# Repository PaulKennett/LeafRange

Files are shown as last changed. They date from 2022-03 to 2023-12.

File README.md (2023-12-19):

# LeafRange
A better range "guess-o-meter" for early Nissan Leaf cars

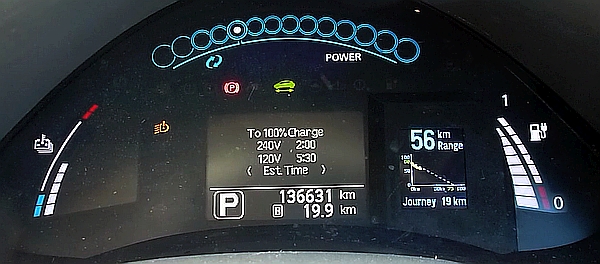
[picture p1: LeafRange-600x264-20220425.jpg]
LeafRange display installed


This project follows on from (and compliments) my earlier [LeafSOCdisplay](https://github.com/PaulKennett/LeafSOCdisplay) project, which grew from [CANa Display for Nissan LEAF](https://ev-olution.yolasite.com/CANa.php) © Copyright EV-OLUTION

The project uses an Ardunio Micro (or Mini Pro, or Mega2650) with a 160x128 pixel TFT display and a MCP2515 CAN-bus module to passively listen to the Car-CAN data bus and use the info to provide a more rational range estimate. The display is mounted in a 3D printed frame that fits *inside* the main dash unit and covers the old range estimate (ie., the "guess-o-meter") with a better range estimate based on battery capacity and temperature. There's also an optional frame that allows the display to be mounted in the corner of the dash, so you can see both the standard Guess-O-Meter and my range estimate.

YouTube drive demo: https://www.youtube.com/watch?v=xt2o3SWRRq8

YouTube hardware show & tell: https://www.youtube.com/watch?v=k4QYvayp_lU

## Features

* range estimate is not stupidly optimistic at the start of your journey (which is usually when you most want it to be rational). You won't see the range estimate drop 10 km after driving the first 1km like the built-in Guess-O-Meter does.
* range estimate does not disappear when the battery dips below 20% (to be replaced by the flashing ---). You get an accurate range estimate down to 0 km. However; there's no buffer below that - so you can't drive another 10 km on "empty" like in a petrol car.
* range chart that shows how well the estiimate matches reality (stores jouurney data in EEPROM over multiple drives)
* shows battery pack temperature in Centigrate (more understandable than the temp "bars") when the battery is cold or hot
* auto-starts a journey odo (multiple trips on a single charge)
* range calculation factors in: battery State of Charge, battery State of Health, and battery temperature (see https://github.com/PaulKennett/LeafRange/wiki/Notes}

The significance of the range chart feature is that it makes it much easier to adjust your driving to achieve a desired range.

### For example
Say you need to drive 75 km in your 2011 Leafster. You charge to "100%" which gives you a rage estimate of 82km range on my LeafRange display (not that bad for an old gen 1.0 Leaf). The guess-o-meter would be saying something like "103km" which would be a bold-faced lie. 

So you head off, stopping at a few places along the way (my display saves range and odo data along the way). About half way there you notice that the chart is showing you're actually trending _below_ the initial estimate line - meaning you should start to ease off the speed a little so that you won't run short. 

On the other hand - if you see that you're driving _above_ the initial estimate line then you know you have plenty of capacity to spare so can afford to drive faster.

### Limitations

THe range formula is simple; it's only factors are battery capacity, battery SOH and batter temperature. It doesn't know about terrain, weather, driving conditions, car weight, etc. The key benefits are; (a) it's not stupidly optimistic at the start of a drive, (b) it doesn't stop working at the bottom end, and (c) the chart allows you to adjust your driving behaviour to achieve a desired range. All those things improve your confidence and reduce range anxiety.

The raw_Gids variable is stored as a single byte so can't go above 255. A brand new 24 kWh Leaf has about 281 Gids when full. This puts an upper bound on the range it can deal with of about 130 km (about 160 km on the GOM).

## Hardware

1. Arduino Micro, Mini Pro, or Mega2560 (use a Mega2560 for development, use a Micro or Mini Pro for use in the car as it boots up much faster and uses less power)
2. MCP2515 (CAN bus module)
3. 1.8 inch TFT display 160x128 pixels (like this https://www.aliexpress.com/item/4000016800528.html)
4. TXS0108E 8 Channel Logic Level Shifter (https://www.aliexpress.com/item/4001131536726.html)
5. 10 Position Flat Flex Cable Assembly Receptacle to Solder Tab 4.00" (101.60mm) https://www.digikey.co.nz/product-detail/en/te-connectivity-amp-connectors/A9AAT-1004F/A9AAT-1004F-ND/137494
6. 5V to 3.3V DC-DC Step-Down Power Supply module (https://www.aliexpress.com/item/4001039310587.html)
7. 70CM 10P IDC Flat Ribbon DATA Cable 2.54mm (https://www.aliexpress.com/item/32891063802.html)
8. Male DC3 10 Pin 2x5Pin Right Angle Double Row Pitch 2.54mm (https://www.aliexpress.com/item/32945804425.html)
9. 3D printed frame for the display (https://www.myminifactory.com/object/3d-print-nissan-leaf-range-graph-display-154555)
10. 3D printed project box DRAFT (https://www.tinkercad.com/things/lRlt66oEZCM-leafrange-box-v16 - I'll provide a better link soon}
11. PBC motherboard for a Pro Micro or Pro Mini Arduino (Gerber file provided above or https://oshwlab.com/paulkennett/LeafRange-for-Micro)
12. PCB for level shifter module (Gerber file provided above - you could use https://jlcpcb.com/ to make them)
13. OBD2 plug (like this https://www.aliexpress.com/item/32865761651.html)
14. 97% Mini DC-DC 15V 12V 9V 7.4V to 5V 4A Step-down Power Module https://www.aliexpress.com/item/4001313603033.html

[Parts list](https://docs.google.com/spreadsheets/d/e/2PACX-1vS2Nyihl8SLagP5YnfhvbngJ51losEeNEex3Urd8iOHfg4pMDlcg-ZONYQ7dYSHcnsXQ2ahFD6JTfKS/pubhtml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) with indicative NZ$ and US$ prices (as at 11 May 2022)

Note: LeafRange_v117.ino fills 99% of program memory on a Micro board, 85% on a Por Mini board and 11% on a Mega 2560 board. If I come up with any new fetures ideas I'll need to drop using the Micro board and foxcus on the Pro Mini.

## Relation to the LeafSOC project

The LeafRange project started out as a fork of the LeafSOC project (with a larger 3.3V TFT display to replace the 5V OLED display). So the LeafRange motherboard has been designed to also be used for the LeafSOC project. The on-board jumpers allow you to switch between Car-CAN (for LeafRange) or EV-CAN (for LeafSOC). 

Also: 
* the latest LeafRange motherboard also has the correct dimensions for the OBD2 plug holes. T
* the LeafSOC project uses a 5V OLED display so you can leave the 5V-to-3.3V DC-DC converter off  

## Todo
- see the Wiki Todo page https://github.com/PaulKennett/LeafRange/wiki/Todo

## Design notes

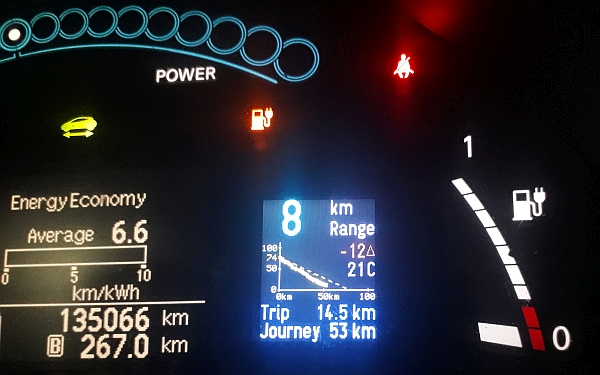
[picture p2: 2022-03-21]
LeafRange_2022-02-21-600x375.jpg

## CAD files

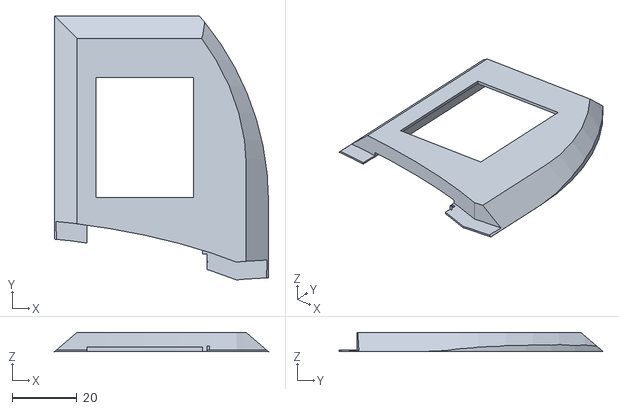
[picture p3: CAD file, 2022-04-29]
LeafRange TFT in-dash frame v03.stl
66.0 x 81.4 x 6.00

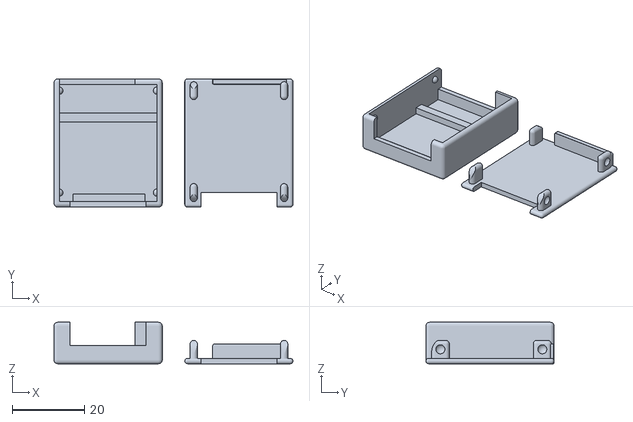
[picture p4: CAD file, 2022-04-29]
LeafRange level shifter box v04.stl
66.2 x 35.5 x 11.5

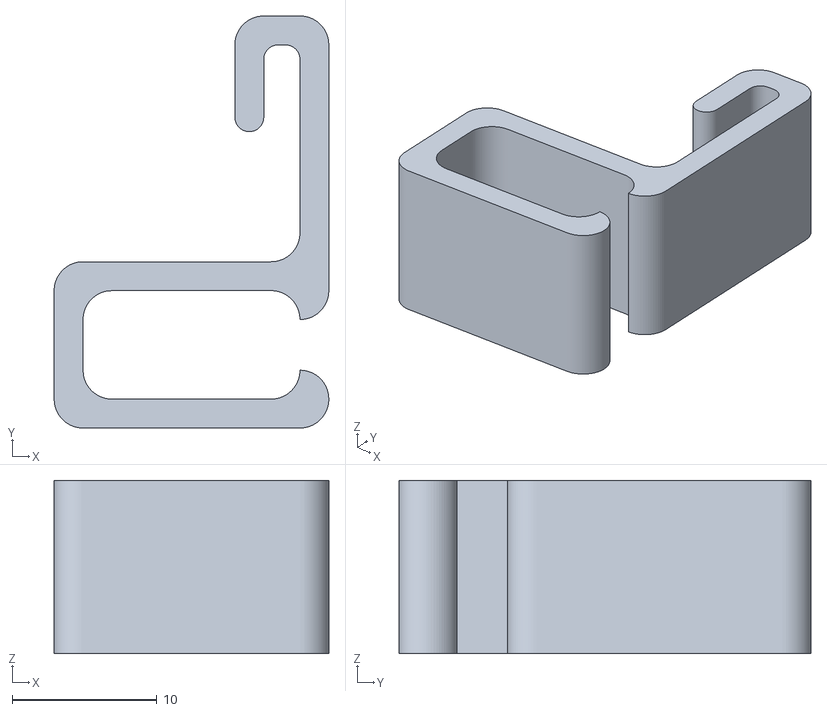
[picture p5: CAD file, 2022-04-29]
Leaf ODB2 cable clip v03.stl
19.0 x 28.5 x 12.0

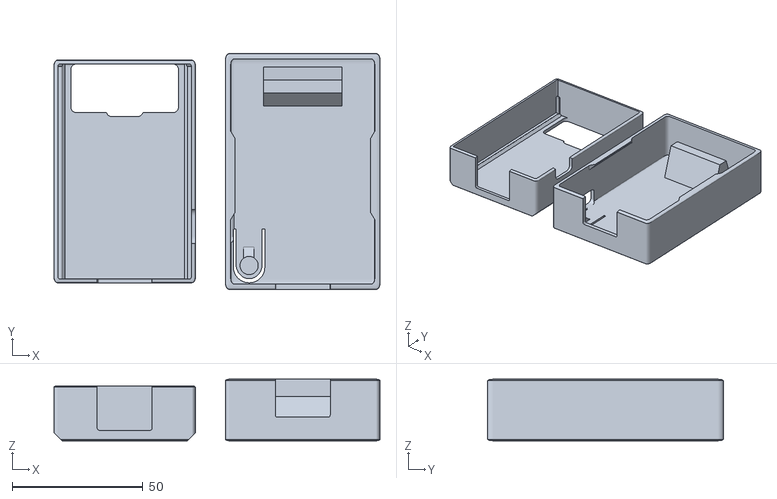
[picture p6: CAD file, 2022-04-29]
LeafRange box for Micro-Mini v04.stl
124.5 x 90.0 x 23.5

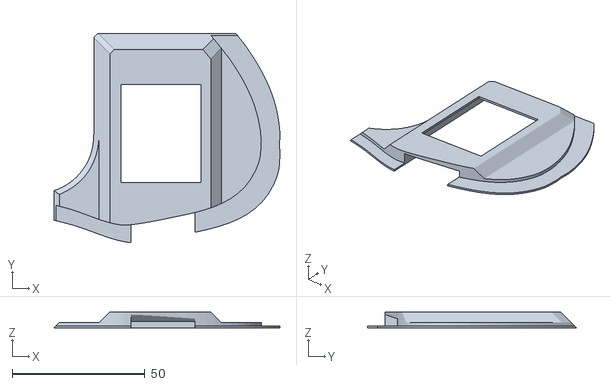
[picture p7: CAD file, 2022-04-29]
LeafRange TFT on-dash frame v11.stl
85.0 x 78.7 x 6.00

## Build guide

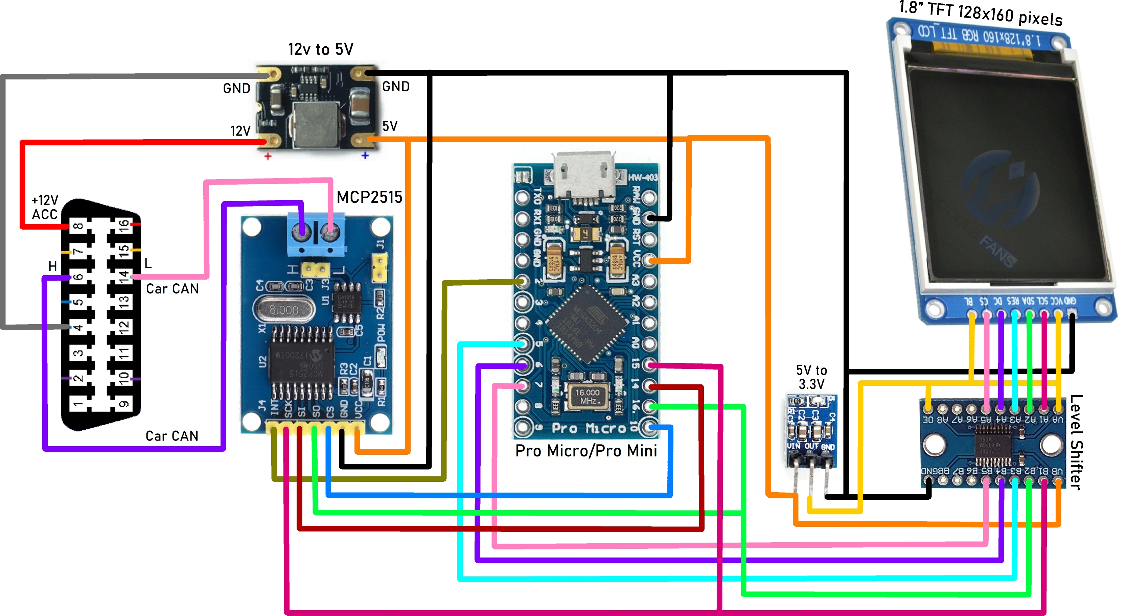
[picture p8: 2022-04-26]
LeafRange wiring diagram 2022-04-26.jpg

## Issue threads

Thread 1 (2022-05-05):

Intermittent interference on Gerber_PCB_LeafRange Micro v0.3C_2022-04-28.zip

PaulKennett, 2022-05-05:
I'm seeing some weird errors on two boards made up using the motherboard.

The range chart shows datapoints in random spots on the graph. After searchign for program bugs my latest hunch is it's a hardware issue.

My current hypothesys is that this is due to interference between the 12V to 5V buck module and the MCP2515 CAN module. This motherboard design has the buck module mounted facing up and the CAN module facing down, directly over it.

I suspect the cheap buck converter (ie a switch mode power supply) is emitting a lot of RF noise directly at the MCP2515 chip. Also the CAN lines from the OBD2 plug run directly under the buck module.

PaulKennett, 2022-05-11:
**Work-around**

Un-solder the module from the motherboard (v0.3C) and have it floating away from the CAN lines and MCP2515. I don't yet know how afar away it needs to be. I've done this to a couple of prototypes and it resolved the data error issue.

**Solution**

I've produced a new version of the motherboard (v0.4A) which moves the buck module further away from the MCP2515.

Hopefully that'll do - but I haven't tested the new board-yet.

Closed 2022-05-11.

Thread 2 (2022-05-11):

X axis scale does no go beyond 100 km

PaulKennett, 2022-05-11:
For cars that (*gasp!*) get more than 100 km range - the X and Y axis scales need to auto-set up to fit the available range.

Could use the battery SOH% value to estimate max range.

1. 66% SOH - my 2011 car max GOM range is 105 km
2. 81.7% SOH - my 2011 car max GOM range was 141 km
3. 83.07 SOH - my 2011 car max GOM range was 150 km
4. 85% SOH - Jodene's 2014 car max GOM is 140 km
5. ??% SOH - Martins 2014 car max GOM is ??? km
6. ??% SOH - Tom's 201? car max GOM is ??? km
7. 81% SOH - John's 2015 car max GOM range is 147 km
8. 79% SOH - John's 2015 car max GOM range is 135 km
9.  ??% SOH - Merewyn's 2011 car max GOM range is ??? km

Here's my rough formula:

max range = 2.23 * SOH - 40

Would help to have a bit more data on battery SOH% vs Guess-O-Meter max range (from cars with less than my 66 SOH%.

PaulKennett, 2022-05-16:
Version 116 fixes this limitation by making the x and y axis scale to 110% that of the initial range.

Closed 2022-05-16.

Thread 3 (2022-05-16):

raw_Gids is stored in a byte

PaulKennett, 2022-05-16:
the raw_gids variable is stored in a byte variable type so the max Gid vlur possible is 255.

A brand new 24kWh Leaf had 281 Gids. My 2011 Leaf had 225 Gids back in 2019 when fully charged.

Are there any 2017 24kWh Leafs with more than 255 Gids left? Maybe - but they probably wont be interested in this project.

If I had to store raw_Gids as a two byte variable in the 1024 byte Micro/Pro Mini EEPROM it would mean I could only store 335 Gid&Odo entries, instead of the 503 entries currently.

PaulKennett, 2022-05-16:
I think this limitation is OK for now.

But, if I ever upgraded to a system with a larger EEPROM then it would be worth switching to storing Gids in 2 bytes.

Closed 2022-05-16.

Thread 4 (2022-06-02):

Intermittent: when car is on but not just sitting for a while LeafRange can slip in to Charging graph mode

PaulKennett, 2022-06-02:
Which causes the Journey odo to reset to zero

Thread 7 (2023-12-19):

Possible improvements

klasrocket, 2023-12-19:
Hi.

Got inspired by your project and started puting toghether something that could also work for 2018+ 40KWh leafs, as I own an old 2012 but borrows a 2018 sometimes for longer trips.
I had the idea to use esp32 instead of arduino for a few reasons, ie. being able to share SoC readings with other services wirelessly, maybe home assistant and/or a better route planner, also esp32 require fewer components, as it's 3.3v and has can-controller built in.
Got it working fairly well at the old leaf but just realized that the newer leafs need polling on the canbus to get anything out at all. Trying to get that working now with help of dalas repo and links: https://github.com/dalathegreat/leaf_can_bus_messages

PaulKennett, 2023-12-19:
I've been thinking about jumping to esp32 also. And I've been borrowing a 30kWh Leafs from time to time. Keen to see what you come up with.

klasrocket, 2023-12-19:
Another thing that might be useful with esp32 is the ability to use a browser on a phone or tablet instead of display, or in combination for more details.
Just managed to get the polling right to read back shifter position so at least some progress. Getting late here in sweden but will contiune a bit the coming days. Hopefully I can get back with something useful in a bit.

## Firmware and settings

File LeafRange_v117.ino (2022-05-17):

// ================================================
// LeafRange by Paul Kennett, 2022
/*
  Started from "CANa Display for Nissan LEAF"  https://ev-olution.yolasite.com/CANa.php © Copyright EV-OLUTION
  Modified by Paul Kennett to use a 128x160 TFT dsiplay and added Range functions.
  For Arduino Mega2650, Micro and Pro Mini boards
  For Arduino Micro and Mini - works by subtracting debug data out to serial port code
  The MCP2515 CAN module is connected to Vehicle-CAN ("Car-CAN") on the OBD2 socket
  See https://paulkennett.github.io/LeafRange/ for full project details

  v117 17 May 2022  refining the charge graph routine
  v116 16 May 2022  made the range chart auto scale to fit initial range
  v115 15 May 2022  refining the charge graph routine
  v114 14 May 2022  made the x & y axis auto-scale
  v113 25 Apr 2022  moved Odo test display section off to a function (cleaner)
  v112 19 Apr 2022  fixed temperature display bug
  v111 18 Apr 2022  Aaargh! Why doesn't the odo reading in Jodene's 2014 Leaf work anymore?!?
  v111 17 Apr 2022  moved counter_pointer in EEPROM to location 4 (and 5) to see if that fixes new odo bug
  v110 16 Apr 2022  fixed bugs produced yesterday
  v109 15 Apr 2022  fixed bugs during drive to Tauranga in Gen 1.1 Leaf
  v108 10 Apr 2022  trying to fix charge/drive mode switching
  v107 10 Apr 2022  watthours_per_gid now derived from raw_battery_soh
  v106 09 Apr 2022  testing in Jodene's 2014 Leaf:
                    (1) raw_gids glitches 38 to 81
                    (2) Range is too pessimistic - need to factor in battery SOH
                    (3) Her SOH 2014 Leaf = 85, my SOH 2011 Leaf = 66
                    (4) Her WH_PER_GID = ???,   my WH_PER_GID 74.0F
  v105 06 Apr 2022  adding charge mode gridelines
  v104 06 Apr 2022  change charging mode x axis to 0 to 50 minutes
  v103 02 Apr 2022  Fixing Charging mode bug: after fast charge did not reset pionter when driving
  v102 31 Mar 2022  Fixing bug: Charging mode while driving
  v101 31 Mar 2022  Fixing bugs in the Charging mode
  v100 30 Mar 2022  starting to work on Charging mode feature
  v88  25 Mar 2022  replacing range_error with range + journey_odo on x axis
  v87  24 Mar 2022  tweaked the range error UI
  v86  23 Mar 2022  tweaked some colours
  v86  20 Mar 2022  optimizing code to fit into the Micro. It works!
  v85  19 Mar 2022  tidying up
*/

#define NAME    "LeafRange"
#define VERSION "Version 117"
#define DATE    "17 May 2022"
#define AUTHOR  "Paul Kennett"

#ifdef __AVR_ATmega2560__       // Debug mode only works on the Mega2650 board. The Micro and Mini don't haven enough program memory
bool debug_mode = false;        // Serial port debug verbosity. Turn ON by changing [false] to [true]. It will slow everything down a lot.
#endif

#include <Adafruit_GFX.h>       // by Limor Fried/Ladyada for Adafruit Industries
#include <Adafruit_ST7735.h>    // Hardware-specific library for ST7735 TFT display
#include <mcp_can.h>            // OBD2 CAN module
#include <EEPROM.h>             // read/write to the EEPROM memory
#include <Fonts/Logisoso_reduced11pt7b.h>
#include <Fonts/Logisoso_compact30pt7b.h>

#define BLACK         0x0000
#define RED           0x001F
#define ORANGE        0x041F
#define GREEN         0x07E0
#define YELLOW        0x07FF
#define LIGHT_YELLOW  0x479C
#define LIGHT_BROWN   0x061D
#define GREY          0x8410
#define LIGHT_GREY    0xC618
#define LIGHTER_GREY  0xE71C
#define LIGHTEST_GREY 0xF79E
#define CYAN          0xFFE0
#define CYAN2         0x8400
#define LIGHTER_BLUE  0xFED6
#define LIGHT_BLUE    0xFE10
#define WHITE         0xFFFF

// Car-CAN (0x174,3) raw_shifter_position vlues
#define PARK          170
#define DRIVE         187
#define REVERSE       153

#define GIDS_TURTLE 8          // raw Gids-8 (the number of Gids to reach Turtle mode)
#define MILES_TO_KM 1.609344F  // conversion factor
#define CAN0_INT    2          // Set CAN0 INTerupt to pin 2
#define TFT_CS      7
#define TFT_RST     5
#define TFT_DC      6

#ifdef __AVR_ATmega2560__
#define EEPROM_SIZE 2047
#else
#define EEPROM_SIZE 1023       // currently experimenting with using just 1K of EEPROM, even on the Mega2560
#endif

#define EEPROM_ADDR_TEST 0     // EEPROM address for the test byte. If not what's expected then this must be a fresh board, so format the whole EEPROM
#define EEPROM_ADDR_DATA 4     // EEPROM address for the data pointer (2 bytes: 4 and 5)
#define EEPROM_ADDR_DATA_START 16  // EEPROM address where the raw_gids/Odo_km data starts 
#define EEPROM_ADDR_DATA_END EEPROM_SIZE  // EEPROM address where the raw_gids/Odo_km data ends (Might as well make it EEPROM_SIZE until I think of something better.)
#define EEPROM_TEST_BYTE 151   // if EEPROM(0) is not this value then assume it's a new board so will format EEPROM
#define CHARGE_TEST_OFFSET 9   // Last_Gids plus this number is compared with raw_gids (first time thru main loop) to test if the car has just been charged

#define LINE1 20               // Y position for top line of text in start-up message
#define LINE2 42               // 2nd line of text
#define LINE3 64               // 3rd line
#define LINE4 98               // 4th line
#define LINE5 120              // 5th line
#define LINE6 130              // 6th line
#define DISPLAY_WIDTH 127      // from 0
#define DISPLAY_HEIGHT 160     // from 0
#define PLOT_TOP 37            // from top of display
#define PLOT_TOP_MARGIN 20     // from top of plot space to top line
#define PLOT_BOTTOM 33         // from bottom of display
#define PLOT_BOTTOM_MARGIN 12  // 
#define PLOT_LEFT 20           // from left side of display
#define PLOT_RIGHT 0           // from right side of display [was 27]
#define FONT_HALF_HEIGHT 4     // for gridline lables
#define PUSH_BUTTON1 8         // currently used for testing

byte plot_width      = DISPLAY_WIDTH - PLOT_LEFT - PLOT_RIGHT;
byte plot_top        = PLOT_TOP + PLOT_TOP_MARGIN;
byte plot_bottom     = DISPLAY_HEIGHT - PLOT_BOTTOM - PLOT_BOTTOM_MARGIN;
byte plot_height     = plot_bottom - plot_top;
byte plot_middle     = plot_top + (plot_height / 2);
byte scale_xy        = 100; // default
float scale_y;
float scale_x;
float odo_conversion = MILES_TO_KM;

long unsigned int rx_id;       // CAN message ID
byte len;                      // data length
byte rx_buf[8];                // 8 byte
//uint16_t raw_gids;           // raw Gids from Vehicle CAN bus x5b3
//uint16_t raw_gids2;          // raw Gids from Vehicle CAN bus x5b3
byte raw_gids;                 // raw Gids from Vehicle CAN bus x5b3
byte raw_gids2;                // raw Gids from Vehicle CAN bus x5b3
unsigned long raw_odo;         // Odometer from Vehicle CAN bus x5c5
byte raw_battery_pack_temp;    // raw battery pack temperature
byte raw_battery_soh;          // battery State of Health %
byte raw_shifter_position;     // Shifter position
byte raw_cluster_units;        // is odo in km or miles?

// Some nomenclature:
// A "trip" (or "leg") means: turn the car on, do some stuff (or not), then turn the car off
// A "journey" is made up of one or more trips/legs. A journey auto-starts when you start the car after a charge session

bool first_time = true;        // used to indicate first time through the main display loop (for driving behaviour)
bool second_time = false;      // used to indicate second time through the main display loop (used for charging behaviour)
bool charging = false;         // true when charing
int range;                     // Range estimate
int range_start;               // Range at start of this journey
int range_error;               // the difference between the initial range estimate and the current range + odo
float battery_pack_temp;       // battery pack temperature
float km_per_kWh;              // km per kWh (of course the real value would change with terrain & wind, etc) now derived via battery_pack_temp
float odo_km_start;            // Odo at start of drive session (leg) [presumably this is always zero!?]
float odo_km;                  // Odo in km (leg)
float odo_km2;                 // used to compare if new value has changed from old value
// float journey_odo;             // the distance in km over the journey (multiple legs) since the car was charged
byte journey_odo;             // the distance in km over the journey (multiple legs) since the car was charged
byte journey_odo_first;        // the first value of journey_odo from EEPROM(5) [presumably this is always zero!?]
byte journey_odo_last;         // the last value of journey_odo from previous drive session (leg)
byte eeprom_gids;              // the Gids value in the EEPROM
byte eeprom_gids_last;         // the last Gids value in EEPROM
unsigned int data_pointer;     // used to cound each time some fresh data is recieved from the CAN bus
float watthours_per_gid;       // value of this is now calculated via battery SOH

// for timestamps in the debug data going out to the serial port.
unsigned long all_seconds;
int run_hours;
int run_minutes;
int run_seconds;
int secs_remaining;


MCP_CAN CAN0(10);              // Set CS for MCP2515 module to pin 10

Adafruit_ST7735 tft = Adafruit_ST7735(TFT_CS, TFT_DC, TFT_RST);


// ============================================================================================
// ============================================================================================
// ============================================================================================


void setup() {

  // temp hacking
  // EEPROM.update(EEPROM_ADDR_TEST, 0); // Uncomment this line if you want to "manually" reformat the EEPROM. Upload & run once. Then recomment this line and upload & run.



  if (EEPROM.read(EEPROM_ADDR_TEST) != EEPROM_TEST_BYTE ) { // auto-format the EEPROM the first time this sketch is run on a board
    format_eeprom();
  }

#ifdef __AVR_ATmega2560__
  if (debug_mode) {
    Serial.begin(9600);
    copy_eeprom_to_serial_port(PUSH_BUTTON1);  // dump the whole EEPROM out the derial port
  }
#endif

  pinMode(PUSH_BUTTON1, INPUT_PULLUP);    // push button on LeafRange PCB

  // read the EEPROM
  data_pointer =  read_unsigned_int_from_eeprom(EEPROM_ADDR_DATA);
  journey_odo_last = EEPROM.read(data_pointer - 2); // reading data_pointer - 2 because data_pointer gets incremented at the end of the main loop [but what if it's a newly formatted EEPROM?!]
  eeprom_gids_last = EEPROM.read(data_pointer - 1);


#ifdef __AVR_ATmega2560__
  if (debug_mode) {
    sprint_setup_data();
  }
#endif

  tft.initR(INITR_GREENTAB);  // Init ST7735S chip, "green tab" variation
  tft.setRotation(2);
  tft.fillScreen(BLACK);
  tft.setTextWrap(false);
  tft.setTextColor(YELLOW);

#ifdef __AVR_ATmega2560__
  if (debug_mode) {
    Serial.println("------------------- Initialise MCP2515 CANbus Module");
  }
#endif

  if (CAN0.begin(MCP_ANY, CAN_500KBPS, MCP_8MHZ) == CAN_OK) {
    mcp2515_boot_message(); // Show version and date. Also functions as delay to get connection to MCP CANbus module running
  } else {
    mcp2515_error_message();
  }

#ifdef __AVR_ATmega2560__
  if (debug_mode) {
    sprint_time_since_boot();
    Serial.println("----------------------------------------------------");
  }
#endif

  CAN0.setMode(MCP_NORMAL);                     // Set operation mode to normal so the MCP2515 sends acks to received data.
  pinMode(CAN0_INT, INPUT);

  tft.setCursor(44, 155); tft.print("Loading...");

#ifdef __AVR_ATmega2560__
  if (debug_mode) {
    Serial.print("===================================== end setup loop\r\n\r\n");
  }
#endif

} // End setup


// ============================================================================================
// ============================================================================================
// ============================================================================================


void loop() {


  // grab a scoop of data from the Car-CAN bus using the MCP2515

  if (!digitalRead(CAN0_INT)) {                   // If CAN0_INT pin is low, read receive buffer
    CAN0.readMsgBuf(&rx_id, &len, rx_buf);        // Read data: len = data length, buf = data byte(s)
    if (rx_id == 0x174) {
      raw_shifter_position = (rx_buf[3]);
    } else if (rx_id == 0x355) {
      raw_cluster_units = (rx_buf[6]);
      if (raw_cluster_units == 64) { // 64 = km, 96 = miles
        odo_conversion = 1;
      }
    } else if (rx_id == 0x5b3) {
      raw_battery_pack_temp = (rx_buf[0]);
      raw_battery_soh = (rx_buf[1]) >> 1;
      raw_gids = constrain((rx_buf[5]), 0, 255); // contrained to fit in one byte
    } else if (rx_id == 0x5c5) {
      raw_odo = (rx_buf[1] << 16 | rx_buf[2] << 8 | rx_buf[3]);
      if (odo_km_start == 0) {
        odo_km_start = (float)raw_odo * odo_conversion;
      } else {
        odo_km = ((float)raw_odo * odo_conversion) - odo_km_start;
      }
    }
  }
  // end grab CAN bus data

  // for testing at my desk
  /*
      raw_shifter_position = DRIVE;  // use PARK to test charging
      raw_cluster_units = 96;
      raw_battery_pack_temp = 95;
      raw_battery_soh = 66;   // my 2011 battery SOH = 66, Jodene's 2014 battery SOH = 85
      //raw_gids = 255;
      raw_gids = EEPROM.read(EEPROM_ADDR_DATA_START + 1);
      //  charging = true;
      //  raw_gids2 = 160;
  */

  // If got fresh raw_gids or odo_km - do all the stuff -------------------------------
  if ((raw_gids != 0) && (raw_gids2 != raw_gids || odo_km2 != odo_km)) {

    journey_odo = constrain(journey_odo_last + odo_km, 0, 255); // contrained to fit in a single byte

    if (!charging) {       // update data_pointer and save data to the EEPROM data array
      EEPROM.update(data_pointer, (byte)journey_odo);
      EEPROM.update(data_pointer + 1, (byte)raw_gids);
    }

    // calculate some stuff
    battery_pack_temp = (raw_battery_pack_temp / 4) - 10;
    watthours_per_gid = 52.17 + (raw_battery_soh * 0.33); // This seems to work OK (so far)
    km_per_kWh        = 5.05 + (0.1 * battery_pack_temp) - (0.0005 * (pow(battery_pack_temp, 2.1))); // formula is fudged from FlipTheFleet dataset (now tapers at higher temps)
    range             = km_per_kWh * ((raw_gids - GIDS_TURTLE) * watthours_per_gid) / 1000;

    // ----------------------------------------------------------------------------------
    if (second_time) {                    // if this is the second time thru the data loop then test if charging
      if (raw_gids > raw_gids2 && odo_km2 == odo_km && raw_shifter_position == PARK) {         // If second raw_gids value has increased then it must be charging
        charging = true;
        range_start = km_per_kWh * ((EEPROM.read(EEPROM_ADDR_DATA_START + 1) - GIDS_TURTLE) * watthours_per_gid) / 1000;
        print_static_drive_elements();
        data_pointer = EEPROM_ADDR_DATA_START;
        write_unsigned_int_to_eeprom(EEPROM_ADDR_DATA, data_pointer);
        EEPROM.update(data_pointer, 0); // reset first journey_odo value in EEPROM to zero
        journey_odo_last = 0;
        journey_odo = 0;
        EEPROM.update(data_pointer + 1, (byte)raw_gids);
        eeprom_gids_last = raw_gids;
      } else {
        charging = false;
      }
      second_time = false;
    } // end of "second time only" tasks
    // ----------------------------------------------------------------------------------

    // ----------------------------------------------------------------------------------
    // "first time only" tasks: draw a dashed line and plot stored data
    if (first_time) {                    // if this is the first time then save raw_gids to EEPROM max_gids array
      tft.fillScreen(BLACK);

      // Has the car just been charged?
      if (raw_gids > eeprom_gids_last + CHARGE_TEST_OFFSET && !charging) { // If first raw_gids has increased then it must have charged
#ifdef __AVR_ATmega2560__
        if (debug_mode) {
          Serial.println("| Was charging! Reset Drive and Display counters");
        }
#endif
        tft.fillRect(0, 0, 15, 40, YELLOW);
        data_pointer = EEPROM_ADDR_DATA_START;
        write_unsigned_int_to_eeprom(EEPROM_ADDR_DATA, data_pointer);
        EEPROM.update(data_pointer, 0); // reset first journey_odo value in EEPROM to zero
        journey_odo_last = 0;
        journey_odo = 0;
        EEPROM.update(data_pointer + 1, (byte)raw_gids);
        eeprom_gids_last = raw_gids;
      }

      range_start = km_per_kWh * ((EEPROM.read(EEPROM_ADDR_DATA_START + 1) - GIDS_TURTLE) * watthours_per_gid) / 1000;

      scale_xy = range_start * 1.1;
      scale_y = plot_height / (float)scale_xy;
      scale_x = plot_width / (float)scale_xy * 0.95; // 0.95 is to give the x axis a bit of extra run-out beyond the initial range
      print_static_drive_elements();
      int y = plot_bottom - (range_start * scale_y) - 1;
      print_initial_range_on_y_axis(y);
      int x2 = (PLOT_LEFT + (range_start * scale_x));
      draw_dashed_line (x2, y);
      plot_saved_data(); // plot data from EEPROM data array
      first_time = false;
      second_time = true; //
    } // end of "first time only" tasks
    // ----------------------------------------------------------------------------------


#ifdef __AVR_ATmega2560__
    if (debug_mode) {
      sprint_display_update_data();
    }
#endif
    print_range(range);
    print_battery_pack_temp(battery_pack_temp);
    int y = plot_bottom - (range * scale_y) - 1;
    if (charging) {
      sprint_time_since_boot();
      tft.fillRect(PLOT_LEFT + (run_minutes * 2) - 1, y - 1, 3, 3, GREEN); // plot new green range estimate "dot" whilst charging
    } else {
      tft.fillRect(PLOT_LEFT + journey_odo - 1, y - 1, 3, 3, YELLOW);      // plot new yellow range estimate "dot" whilst driving
      // range_error = (range + journey_odo) - range_start;
      // print_range_error(range_error);
      print_odo_plus_range_on_x_axis(range + journey_odo);
      // print_trip_odo(odo_km);
      // print_test_info();
      print_journey_odo(journey_odo);
    }
#ifdef __AVR_ATmega2560__
    if (debug_mode) {
      //   print_info_message(); // print some data for testing
    }
#endif

    // update "has it changed?" variables
    odo_km2 = odo_km;
    raw_gids2 = raw_gids;

    if (data_pointer < EEPROM_ADDR_DATA_END - 2 && !charging) { // don't increment pointer if it's reached the end of the EEPROM
      data_pointer = data_pointer + 2;     // increment data array pointer
      write_unsigned_int_to_eeprom(EEPROM_ADDR_DATA, data_pointer);
    }

#ifdef __AVR_ATmega2560__
    if (debug_mode) {
      sprint_time_since_boot();
      Serial.print("--------------------------- display update loop end\r\n\r\n");
    }
#endif
  } // end of the "got some data" stuff


  // Options for the push button - I haven't tested these properly yet
  // push_button_reset_data_pointer(PUSH_BUTTON1);
  // push_button_format_eeprom(PUSH_BUTTON1);

} // END MAIN LOOP


// ============================================================================================
// ============================================================================================
// ============================================================================================


void mcp2515_boot_message() {
  tft.setFont(&Logisoso_reduced11pt7b);
  tft.setCursor(18, LINE2); tft.print(NAME);
  tft.setTextColor(LIGHT_GREY);
  tft.setCursor(8, LINE3); tft.print(AUTHOR);
  tft.setTextColor(GREY);
  tft.setCursor(7, LINE4); tft.print(DATE);
  tft.setCursor(13, LINE5); tft.print(VERSION);
  delay(1000);
}


void mcp2515_error_message() {
  tft.setFont(&Logisoso_reduced11pt7b);
  tft.setCursor(0, LINE2); tft.print("MCP2515");
  tft.setCursor(0, LINE3); tft.print("error");
  delay(10000);
}


void format_eeprom() {
  for (int i = 0; i <= EEPROM_SIZE; i++) {
    EEPROM.update(i, 0);
  }
  //  EEPROM.update(EEPROM_ADDR_SCALE, DEFAULT_SCALE);
  EEPROM.update(0, EEPROM_TEST_BYTE);
  write_unsigned_int_to_eeprom(EEPROM_ADDR_DATA, EEPROM_ADDR_DATA_START);
}
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

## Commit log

2022-03-21 LeafRange Arduino code v86
    Runs on an Arduino Micro, Mini Pro and Mega2560. When run on the Mega2560 it provides additional functionality to send data out the serial port for debugging.
2022-03-21 STL file for 3D printing the frame for the 1.8 inc h TFT display
    [leaf-dash-frame-for-1p8inch-tft-v09.stl]
2022-04-01 Wiring diagram for the LeafRange
2022-04-01 Added Charging mode
    Now shows a graph of the charge as it increases during a charging session (if you have the car ON during a charge session).
2022-04-26 Add files via upload
    swapped the level shifter (to the one I'm actually using in my prototype)
2022-04-26 Delete LeafRange wiring diagram.jpg
    Replaced with newer version that uses the level shifter I'm using.
2022-04-28 Gerber files for the PCBs
    Generated using EasyEDA. You can use these to get JCLPCB to make the motherboard and level shiifter boards. These are designed for all through-hole parts and modules (not SMD parts).
2022-04-28 Update README.md
    Added Gerber files for the project main board and level shifter board
2022-04-28 Update README.md
    Updated the header image and I've tested the LeafRange on a 2014 Leaf with 85% SOH battery (in addition to my 2011 Leaf with 67% SOH battery).
2022-04-29 STL files
    Note: TFT frame option need support material when printing, whereas the cable clip, level shifter and boxes do not need support material.
    [Leaf ODB2 cable clip v03.stl, LeafRange TFT in-dash frame v03.stl, LeafRange TFT on-dash frame v11.stl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]
2022-04-29 Updated hardware list
    added 70CM 10P IDC Flat Ribbon DATA Cable 2.54mm
2022-05-02 Deleted double item in hardware list
    I had the 70CM 10P IDC Flat Ribbon DATA Cable listed twice
2022-05-02 Added 12v - 5V module to the hardware list
2022-05-05 Moved parts to reduce RF interference
    Moved 12V to 5V buck converter out from under the MCP2515 in the hopes that RF interference will be reduced. Also changed the OBD2 holes to be oblongs to better fit wide pins.
2022-05-05 Delete Gerber_PCB_LeafRange Micro v0.3C_2022-04-28.zip
    superceeded
2022-05-05 Moved parts to reduce IR interference
    Moved the 12V to 5V buck converter out from under the MCOP2515 CAN bus module. I think it was causing spurious data readings.
2022-05-11 Added link to OSHWlab.com PCB files
2022-05-17 x and y axis now auto-scale
    Chart now scales nicely to fit the initial range
2022-06-02 PCB for TSX0108E level shifter
    2 June 2022
2022-06-02 PCB for Micro or Pro Mini
    Added mounting holes in 3 corners
